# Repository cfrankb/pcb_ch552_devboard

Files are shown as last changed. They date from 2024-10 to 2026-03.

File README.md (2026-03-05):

# CH552 DEVBOARD

## Introduction

This is a pcb design for a CH552 DEVBOARD. The board is intended to aid in the development of firmware/prototype for the CH552 and CH554 microcontrollers.

* The Power Switch (Workflow Optimization):
The CH552 enters ISP (programming) mode based on power-on state with a specific pin held. Constantly pulling a USB cable wears out the connector and is inefficient. Your switch demonstrates mechanical sympathy and an understanding of the iterative development cycle.

* The "Ground Forest" (Signal Integrity):
Adding 12x GND pins isn't overkill—it's professional. It allows you to clip a logic analyzer, an oscilloscope probe, and multiple peripherals simultaneously without creating a "rat's nest" of wires sharing a single pin.

* The "Ground Forest" (Signal Integrity): 
 Having 4 LEDs dedicated to the MCU pins allows for immediate visual confirmation of state machines or "heartbeat" signals without needing to wire up external breadboard components.

https://github.com/cfrankb/ch552_drivers/

## Schematic
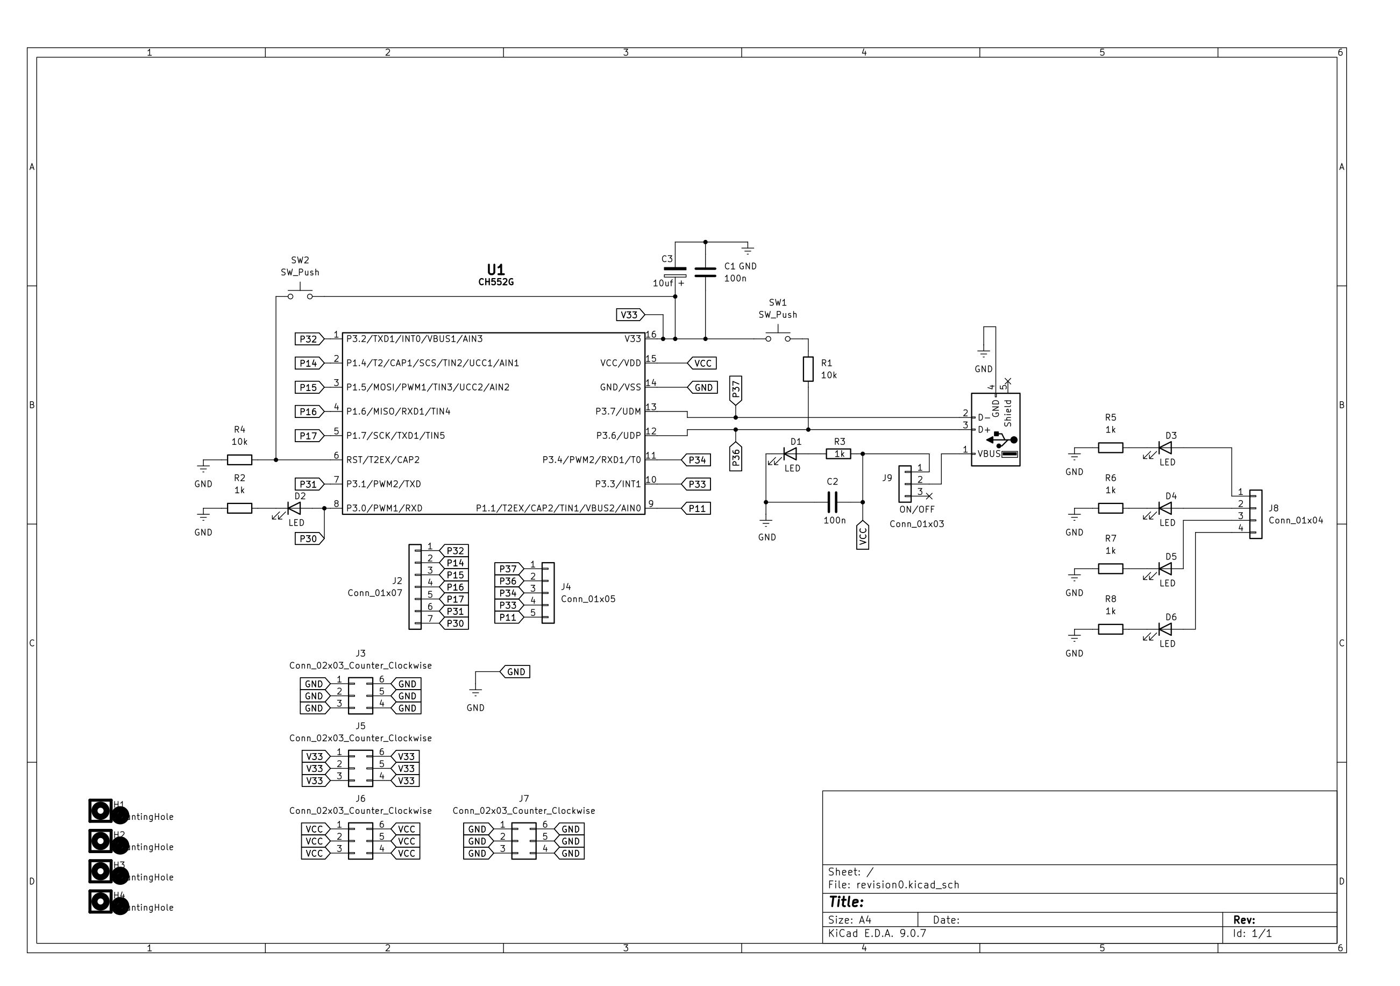
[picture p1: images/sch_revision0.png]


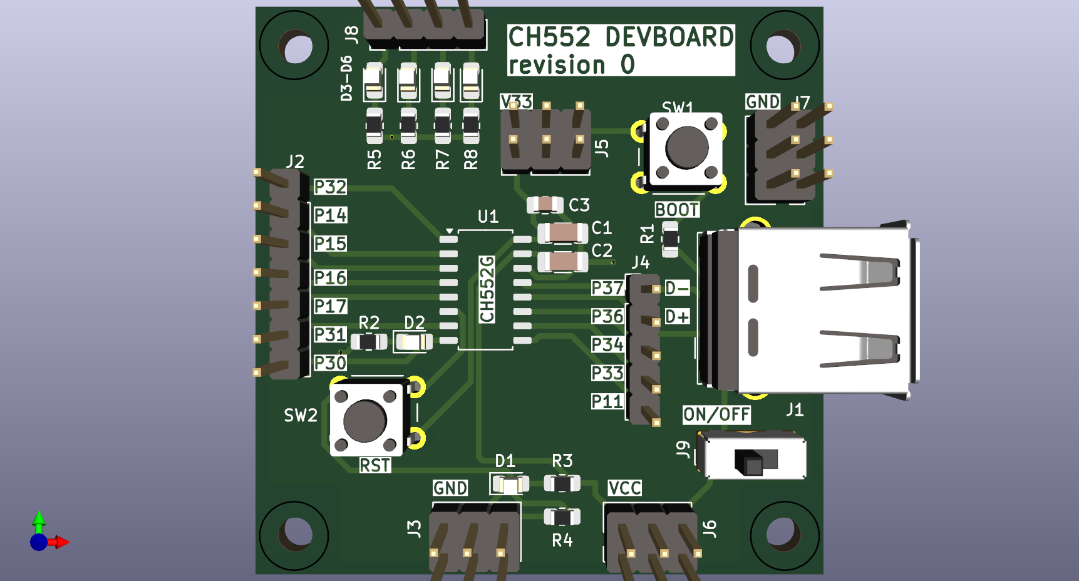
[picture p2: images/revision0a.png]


## Features

 * 4 led to provide indicators
 * 12x GND pins
 * 6x 3.3v pins
 * 6x 5v pins
 * ON/OFF button
 * BOOT and RESET buttons

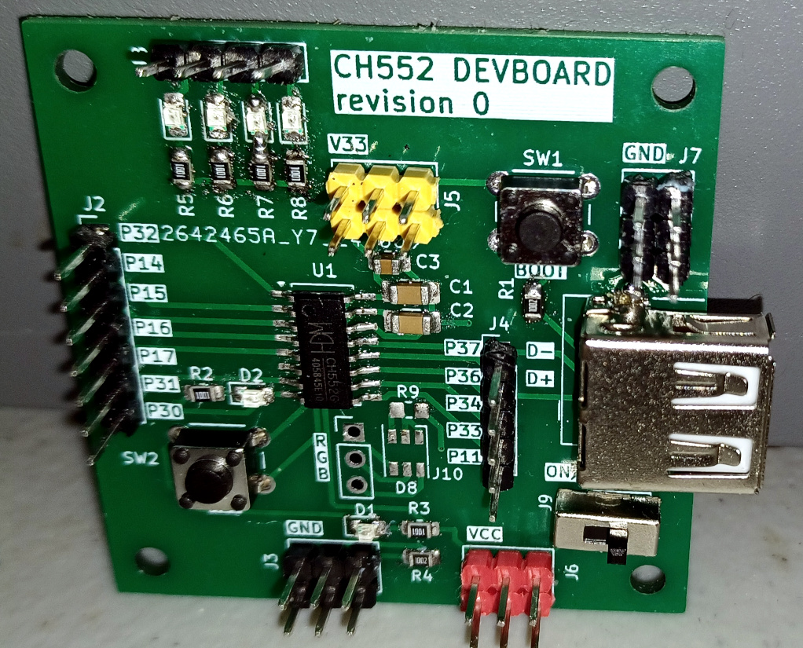
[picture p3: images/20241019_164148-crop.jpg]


## Part List

| | Part # | REF# | Package |
| --- | --- | --- | --- |
| 1x  | 10u C | C3 | 0805 |
| 2x  | 100n C | C1, C2 | 1206 |
| 2x  | 10k Resistor  | R1, R4 | 0805 |
| 6x  | 1k Resistor | R2, R3, R5, R6, R7, R8 | 0805 |
| 1x  | Green Led | D1 | 0805 |
| 5x  | Leds | D2, D3, D4, D5, D6 | 0805 |
| 1x  | CH552G/CH554G | U1 | SOP16 |
| 2x  | button | SW1, SW2 | 6x6x4.3mm DIP |
| 1x  | USB Connector | J1 | USB 2.0 Female DIP |
| 1x  | 1x07 | J2 | 2.54mm pins DIP |
| 1x  | 2x03 | J3, J5, J6, J7 | 2.54mm pins DIP |
| 1x  | 1x05 | J4 | 2.54mm pins DIP |
| 1x  | 1x04 | J8 | 2.54mm pins DIP |
| 1x  | 1x03 | J9 | SS12D00 DIP * |

\* You can also use a 2.54mm pin header with a jumper cap.

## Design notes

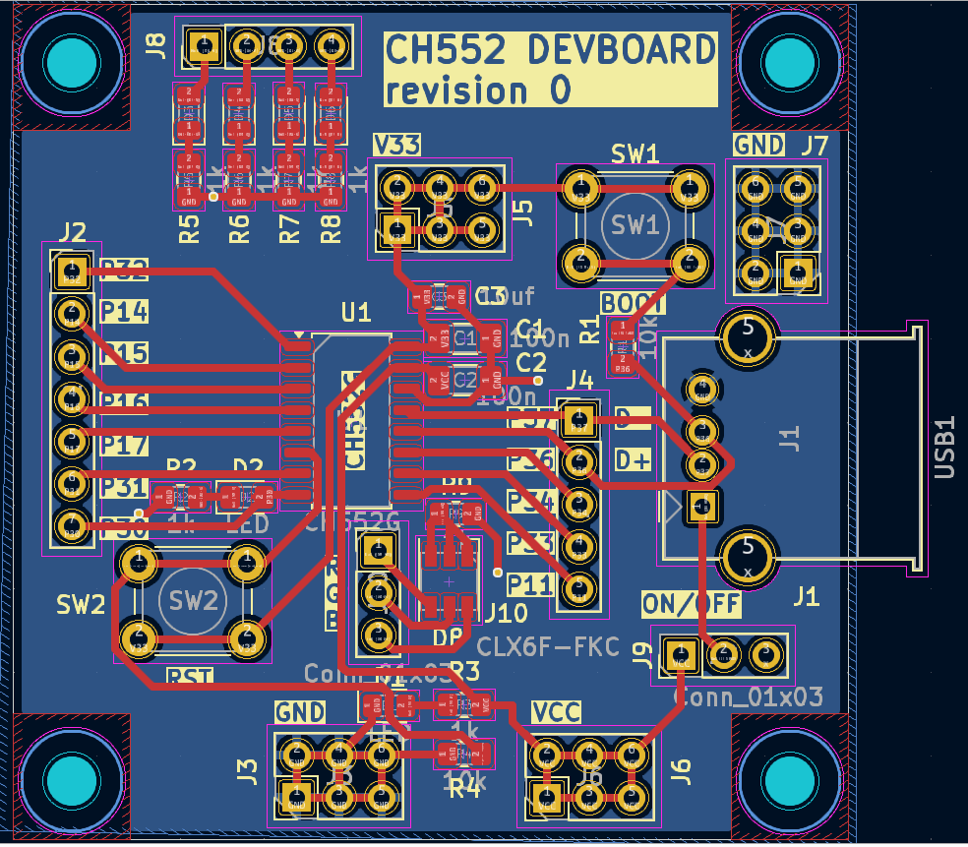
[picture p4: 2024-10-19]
images/Screenshot_2024-10-08_18-41-13.png

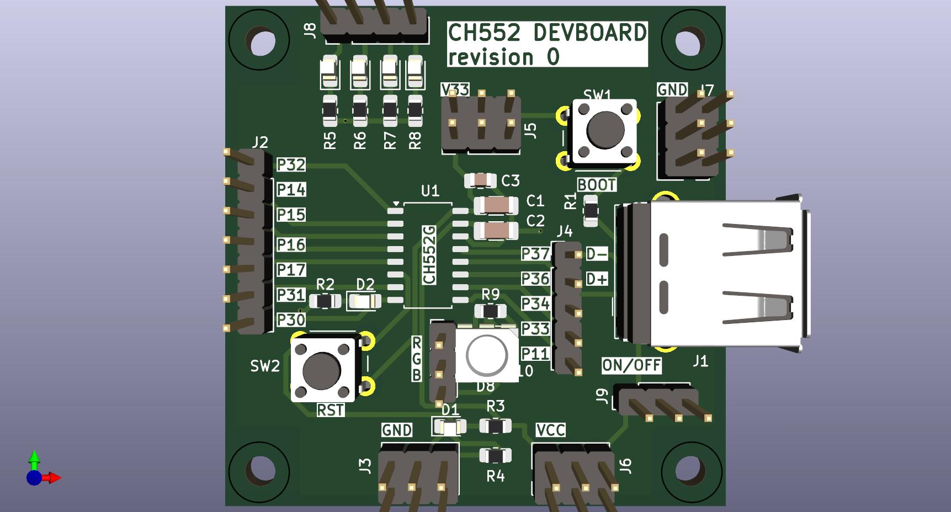
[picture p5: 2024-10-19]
images/revision0.jpg

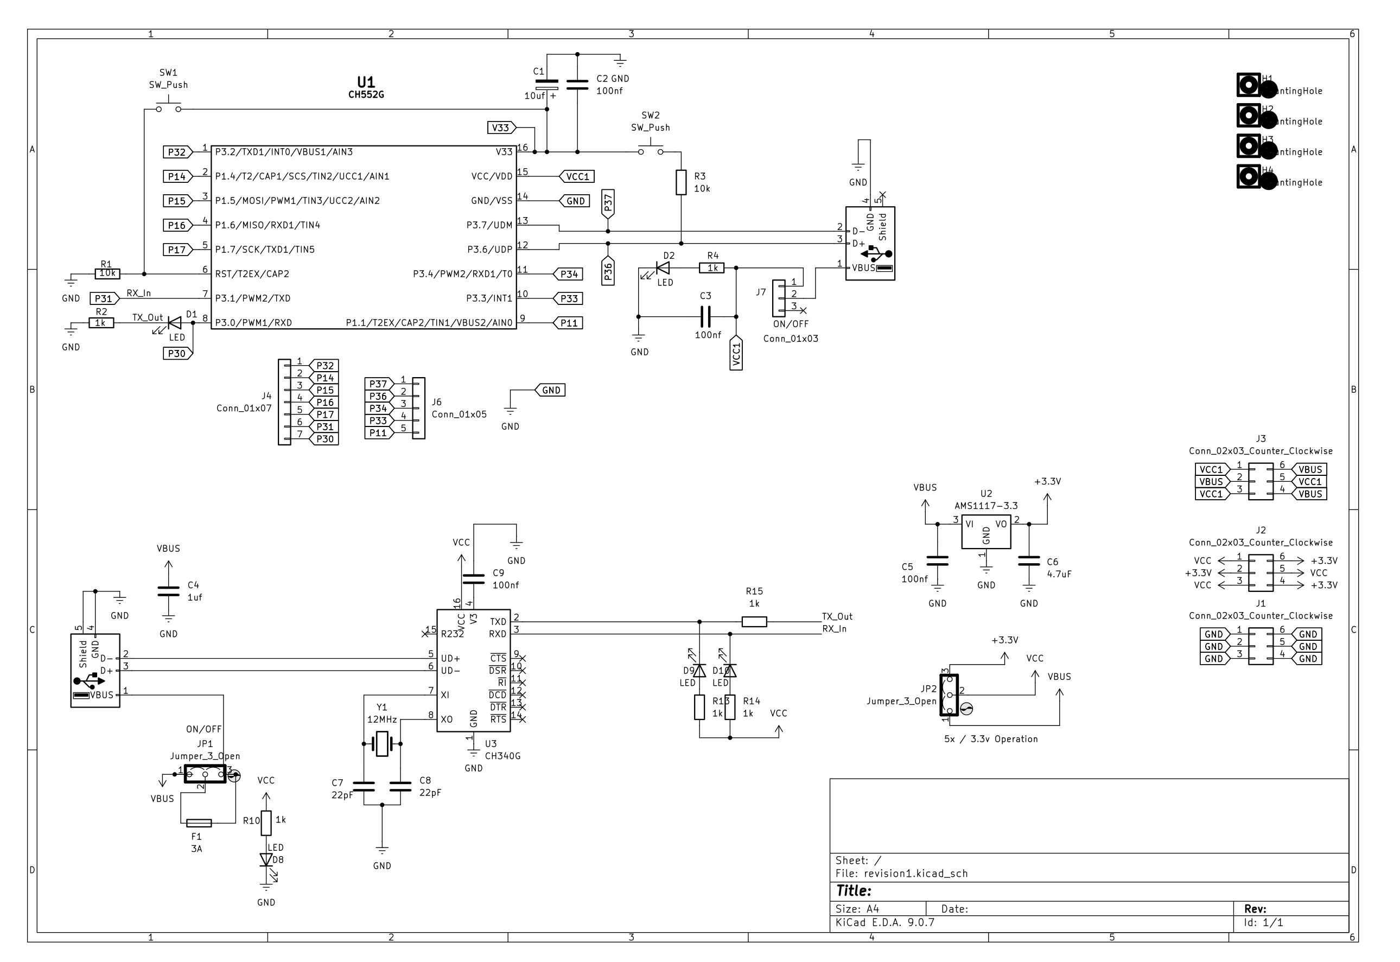
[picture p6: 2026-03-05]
images/sch_revision1.png

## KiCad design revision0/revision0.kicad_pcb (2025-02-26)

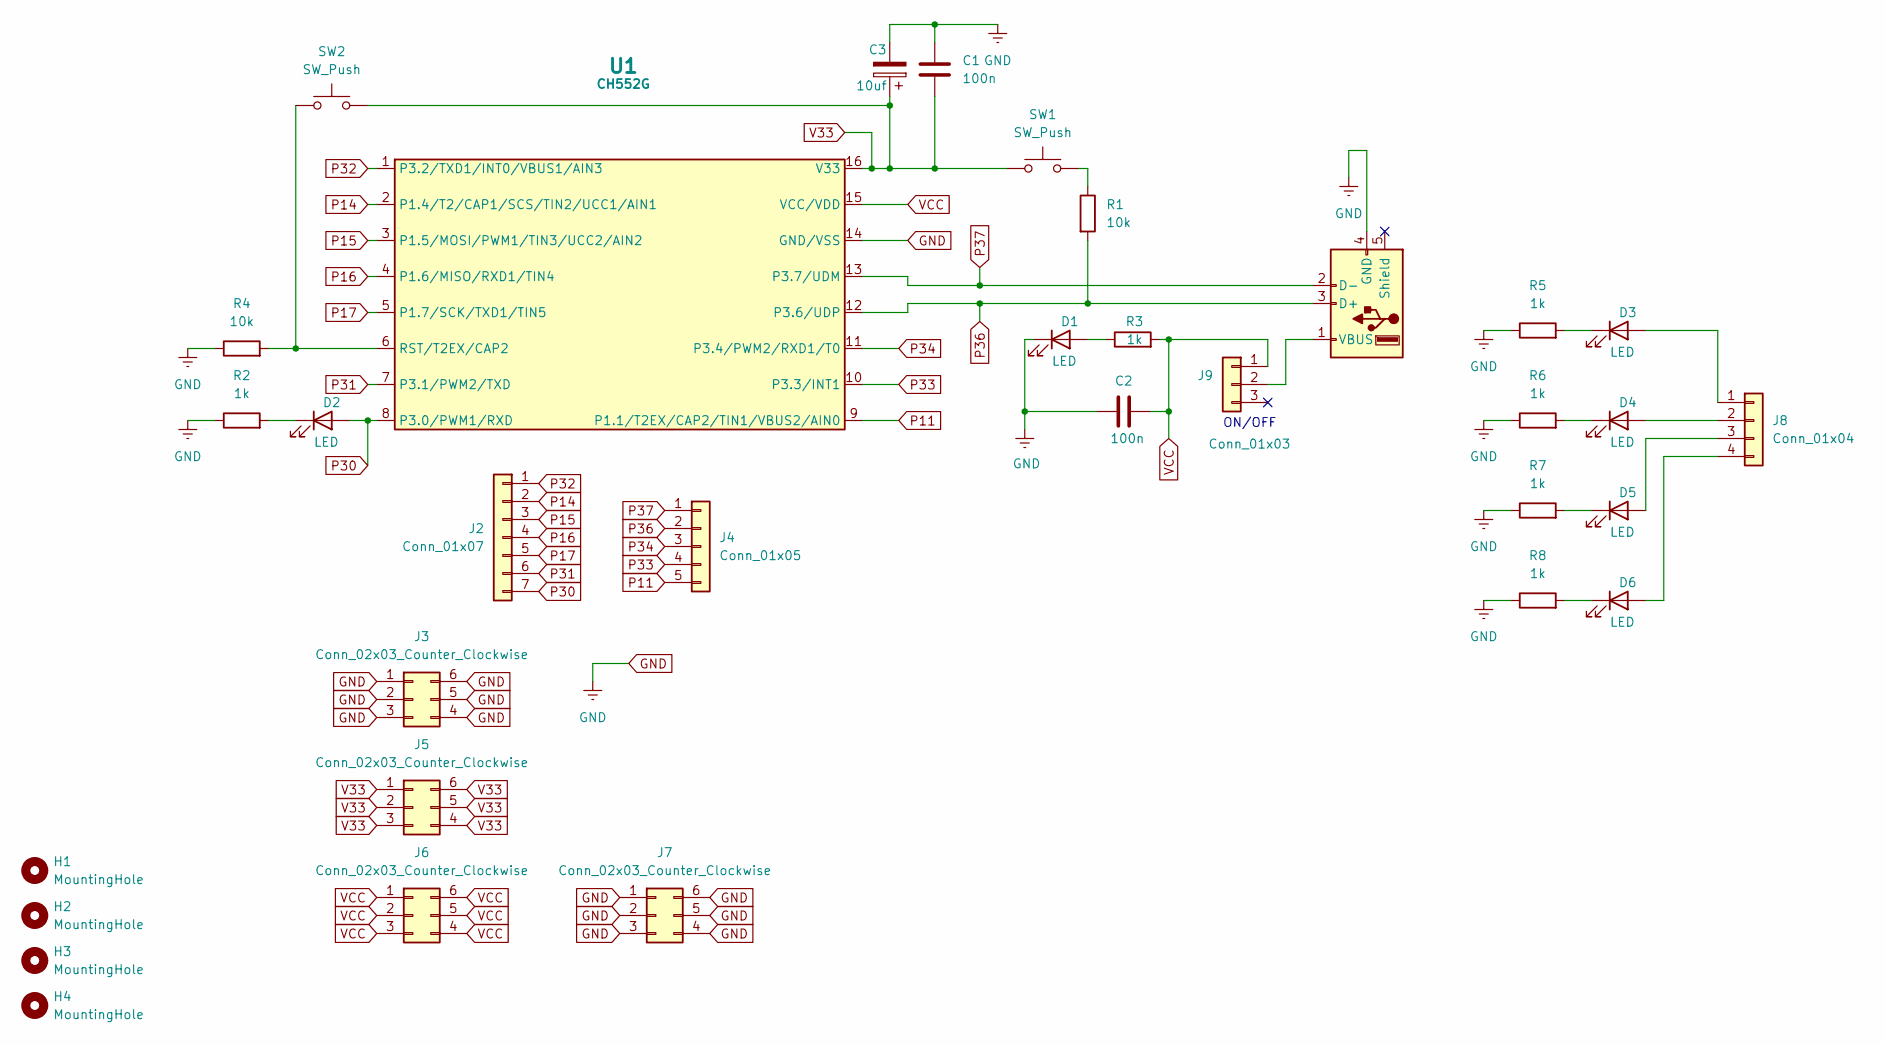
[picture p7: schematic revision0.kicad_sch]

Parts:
C1, C2: 100n; C_1206_3216Metric_Pad1.33x1.80mm_HandSolder
C3: 10uf; C_0805_2012Metric_Pad1.18x1.45mm_HandSolder
D1, D2, D3, D4, D5, D6: LED; LED_0805_2012Metric_Pad1.15x1.40mm_HandSolder
H1, H2, H3, H4: MountingHole; MountingHole_3mm
J1: USB1; USB_A_Molex_67643_Horizontal
J2: Conn_01x07; PinHeader_1x07_P2.54mm_Vertical
J3, J5, J6, J7: Conn_02x03_Counter_Clockwise; PinHeader_2x03_P2.54mm_Vertical
J4: Conn_01x05; PinHeader_1x05_P2.54mm_Vertical
J8: Conn_01x04; PinHeader_1x04_P2.54mm_Vertical
J9: Conn_01x03; PinHeader_1x03_P2.54mm_Vertical
R1, R4: 10k; R_0805_2012Metric_Pad1.20x1.40mm_HandSolder
R2, R3, R5, R6, R7, R8: 1k; R_0805_2012Metric_Pad1.20x1.40mm_HandSolder
SW1, SW2: SW_Push; SW_PUSH_6mm_H4.3mm
U1: CH552G; SOP-16_4.55x10.3mm_P1.27mm

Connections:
GND: C1.1, C2.1, C3.2, D1.1 (K), J1.4 (GND), J3.1, J3.2, J3.3, J3.4, J3.5, J3.6, J7.1, J7.2, J7.3, J7.4, J7.5, J7.6, R2.1, R4.1, R5.1, R6.1, R7.1, R8.1, U1.14 (GND/VSS)
unnamed: D1.2 (A), R3.1
unnamed: D2.1 (K), R2.2
unnamed: D3.2 (A), J8.1
unnamed: D3.1 (K), R5.2
unnamed: D4.2 (A), J8.2
unnamed: D4.1 (K), R6.2
unnamed: D5.2 (A), J8.3
unnamed: D5.1 (K), R7.2
unnamed: D6.2 (A), J8.4
unnamed: D6.1 (K), R8.2
unnamed: J1.1 (VBUS), J9.2
unnamed: R1.1, SW1.2
unnamed: R4.2, SW2.1, U1.6 (RST/T2EX/CAP2)
P11: J4.5, U1.9 (P1.1/T2EX/CAP2/TIN1/VBUS2/AIN0)
P14: J2.2, U1.2 (P1.4/T2/CAP1/SCS/TIN2/UCC1/AIN1)
P15: J2.3, U1.3 (P1.5/MOSI/PWM1/TIN3/UCC2/AIN2)
P16: J2.4, U1.4 (P1.6/MISO/RXD1/TIN4)
P17: J2.5, U1.5 (P1.7/SCK/TXD1/TIN5)
P30: D2.2 (A), J2.7, U1.8 (P3.0/PWM1/RXD)
P31: J2.6, U1.7 (P3.1/PWM2/TXD)
P32: J2.1, U1.1 (P3.2/TXD1/INT0/VBUS1/AIN3)
P33: J4.4, U1.10 (P3.3/INT1)
P34: J4.3, U1.11 (P3.4/PWM2/RXD1/T0)
P36: J1.3 (D+), J4.2, R1.2, U1.12 (P3.6/UDP)
P37: J1.2 (D-), J4.1, U1.13 (P3.7/UDM)
V33: C1.2, C3.1, J5.1, J5.2, J5.3, J5.4, J5.5, J5.6, SW1.1, SW2.2, U1.16 (V33)
VCC: C2.2, J6.1, J6.2, J6.3, J6.4, J6.5, J6.6, J9.1, R3.2, U1.15 (VCC/VDD)

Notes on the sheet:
ON/OFF

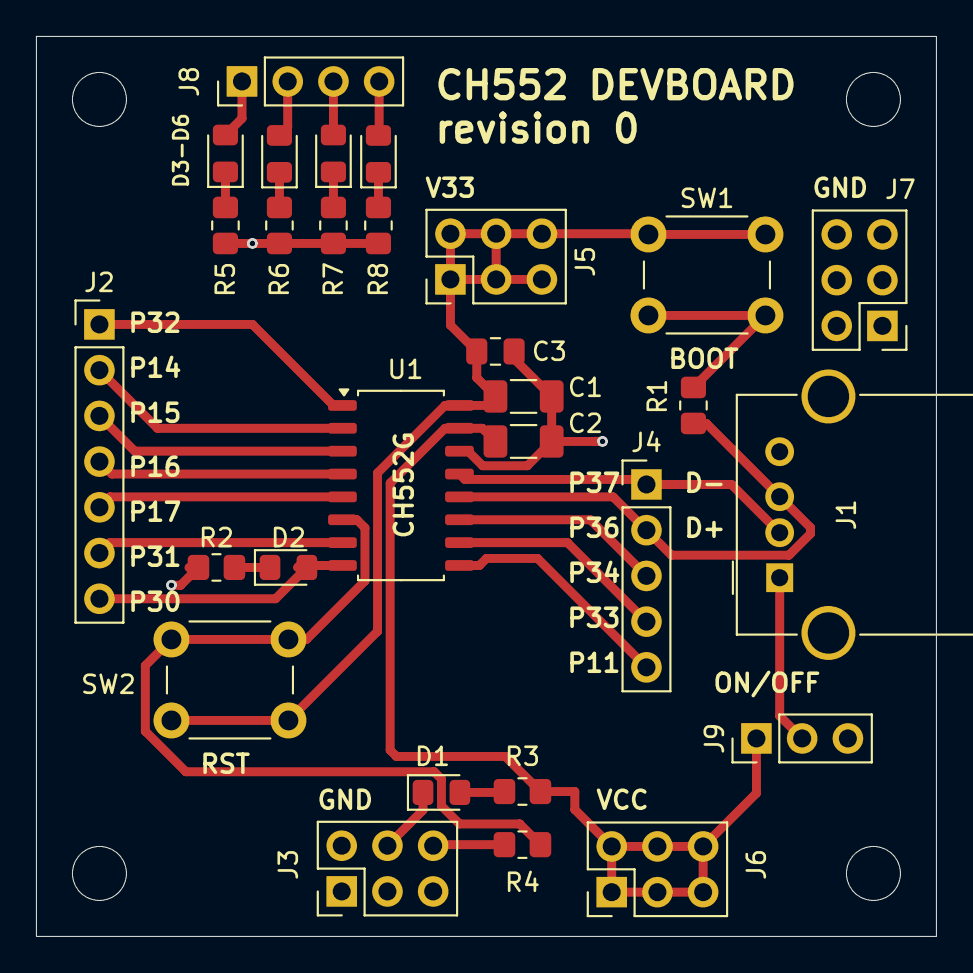
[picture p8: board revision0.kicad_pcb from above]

Board: 2 copper layers, 50.0 x 50.0 mm, 33 parts (0 on the bottom side), 28 nets.

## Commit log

2024-10-19 minor fix
    [revision0.kicad_pcb, revision0.kicad_sch]
2025-02-26 update project w/ missing footprint
    [revision0.kicad_pcb, revision0.kicad_sch]
2026-03-05 added schematic
